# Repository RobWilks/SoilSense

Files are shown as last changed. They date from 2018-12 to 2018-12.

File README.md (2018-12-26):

# SoilSense
Measurement of capacitance of soil probe to determine moisture content of soil
Uses an LC oscillator at f from 50-100MHz
Frequency of oscillation is proportional to the inverse root of capacitance

At these frequencies and temperatures 0 < T < 30 degC the dielectric function of water is ~80; small changes in soil moisture content create a large change in capacitance

There are two physical prototypes, mark I & II:

Mark I
Uses a Clapp oscillator and emitter follower with BC547B transistors.  In the tank circuit is a toroidal inductor of 13-16 turns and 3x 22pF capacitors.
Base input and stray capacitance estimated as 7 and 3 respectively.  

Mark II
Uses a Motorola VCO MC1648 a toroidal inductor of 9 turns and 10pF cpacitor in the tank circuit (adds to input capacitance of 6pF)

Marks I & II use the same prescaler and counter circuits to convert the high frequency oscillation to a low frequency square wave, reducing the frequency by 1/2^17 

The low frequency is measured using a 16MHz 5V Promini and the result sent to a gateway using a cheap 433MHz RF transmitter 

Repository contains:

Clapp circuit 181226.log	:	LTSpice simulation of Clapp oscillator and transmission line

ReadNodeDataNew.R	:	R analysis of data from soil probe

Schematic_Soil-Sense-Mark-1_buffered-Clapp-circuit_20181225231505.pdf	:	Schematic of circuit for SoilSenseMark1 from EasyEDA

SketchVxx.cpp	:	Old - hidden

SoilSenseMark1	:	C++ code for ProMini measurement and reporting sequence

SoilSenseMark2	:	C++ code for ProMini measurement and reporting sequence

SoilSenseMark2_board.pdf	:	Vero board design for SoilSenseMark2 from Eagle

SoilSenseMark2_schematic.pdf	:	Schematic of circuit for SoilSenseMark2 from Eagle

freqCounterV4.brd	:	Vero board design for SoilSenseMark2 from Eagle

freqCounterV4.sch	:	Schematic of circuit for SoilSenseMark2 from Eagle

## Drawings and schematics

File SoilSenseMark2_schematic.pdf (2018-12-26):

100n

1u

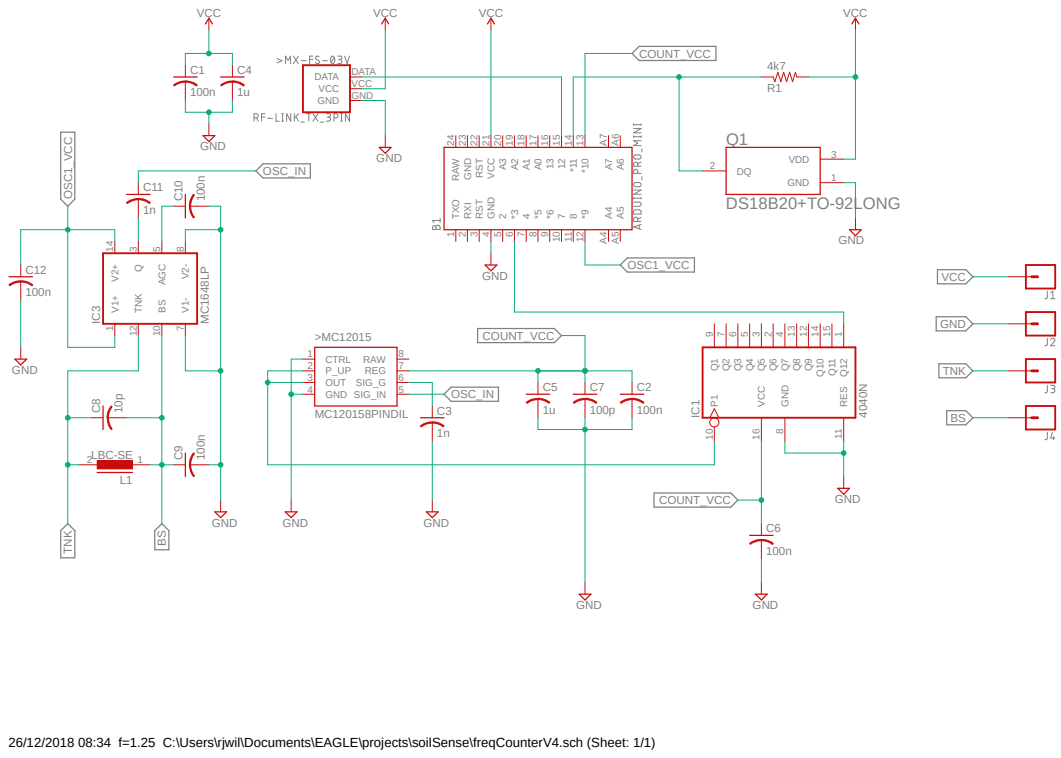
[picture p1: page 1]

26/12/2018 08:34 f=1.25 C:\Users\rjwil\Documents\EAGLE\projects\soilSense\freqCounterV4.sch (Sheet: 1/1)

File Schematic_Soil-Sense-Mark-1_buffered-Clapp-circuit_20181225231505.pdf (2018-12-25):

## probe V(Vout) V(Q4_base) V(Q4_emitter) V(Tank) tran .5n 30u 29.9u

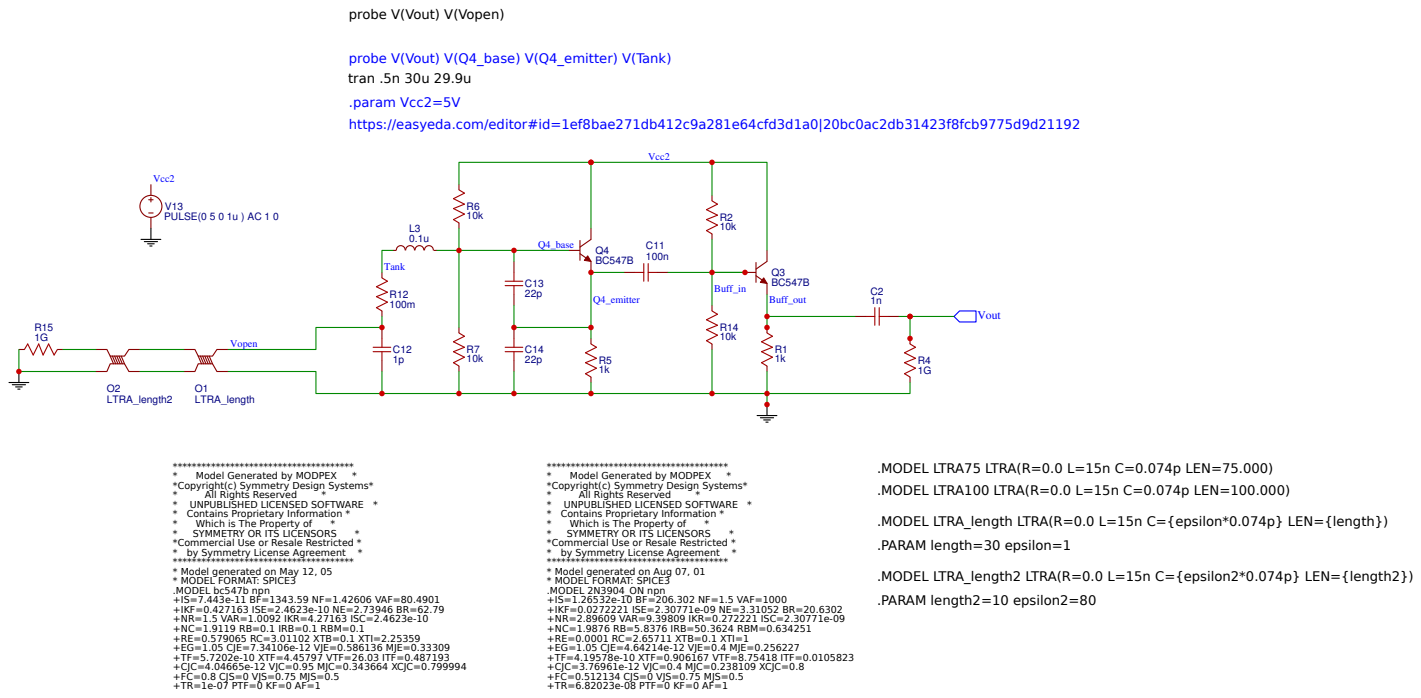
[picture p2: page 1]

.param Vcc2=5V
https://easyeda.com/editor#id=1ef8bae271db412c9a281e64cfd3d1a0|20bc0ac2db31423f8fcb9775d9d21192

*Copyright(c) Symmetry Design Systems*
* UNPUBLISHED LICENSED SOFTWARE *
* Contains Proprietary Information *
*Commercial Use or Resale Restricted *
* by Symmetry License Agreement *
* Model generated on May 12, 05
* MODEL FORMAT: SPICE3
.MODEL bc547b npn
+IS=7.443e-11 BF=1343.59 NF=1.42606 VAF=80.4901
+IKF=0.427163 ISE=2.4623e-10 NE=2.73946 BR=62.79
+NR=1.5 VAR=1.0092 IKR=4.27163 ISC=2.4623e-10
+NC=1.9119 RB=0.1 IRB=0.1 RBM=0.1
+RE=0.579065 RC=3.01102 XTB=0.1 XTI=2.25359
+EG=1.05 CJE=7.34106e-12 VJE=0.586136 MJE=0.33309
+TF=5.7202e-10 XTF=4.45797 VTF=26.03 ITF=0.487193
+CJC=4.04665e-12 VJC=0.95 MJC=0.343664 XCJC=0.799994
+FC=0.8 CJS=0 VJS=0.75 MJS=0.5
+TR=1e-07 PTF=0 KF=0 AF=1

* Model generated on Aug 07, 01
.MODEL 2N3904_ON npn
+IS=1.26532e-10 BF=206.302 NF=1.5 VAF=1000
+IKF=0.0272221 ISE=2.30771e-09 NE=3.31052 BR=20.6302
+NR=2.89609 VAR=9.39809 IKR=0.272221 ISC=2.30771e-09
+NC=1.9876 RB=5.8376 IRB=50.3624 RBM=0.634251
+RE=0.0001 RC=2.65711 XTB=0.1 XTI=1
+EG=1.05 CJE=4.64214e-12 VJE=0.4 MJE=0.256227
+TF=4.19578e-10 XTF=0.906167 VTF=8.75418 ITF=0.0105823
+CJC=3.76961e-12 VJC=0.4 MJC=0.238109 XCJC=0.8
+FC=0.512134 CJS=0 VJS=0.75 MJS=0.5
+TR=6.82023e-08 PTF=0 KF=0 AF=1

.MODEL LTRA_length LTRA(R=0.0 L=15n C={epsilon*0.074p} LEN={length})
.PARAM length=30 epsilon=1

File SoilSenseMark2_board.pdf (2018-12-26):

26/12/2018 08:36 f=3.00 C:\Users\rjwil\Documents\EAGLE\projects\soilSense\freqCounterV4.brd

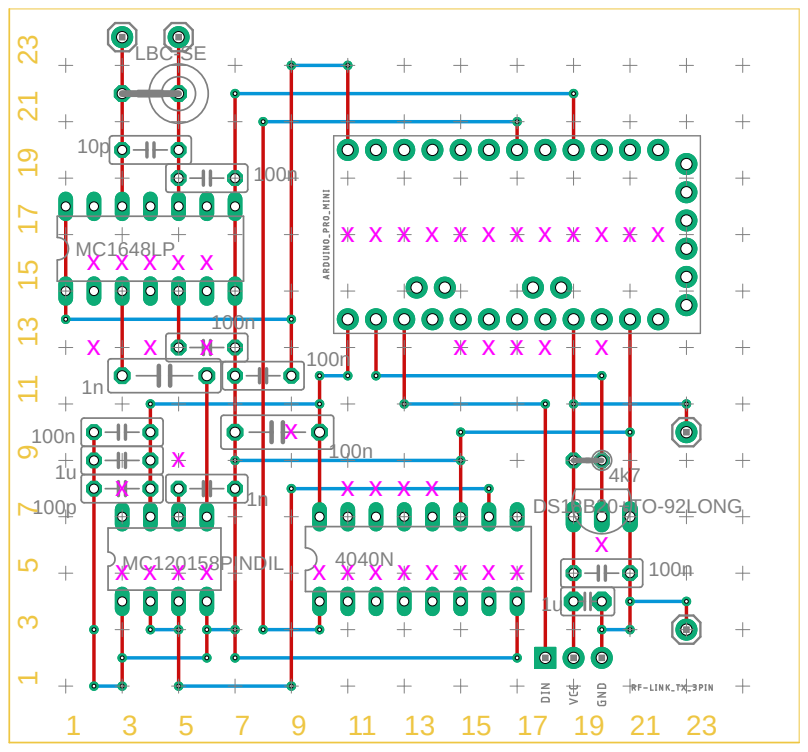
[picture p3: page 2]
MC120158PINDIL; DS18B20+TO-92LONG; LBC-SE

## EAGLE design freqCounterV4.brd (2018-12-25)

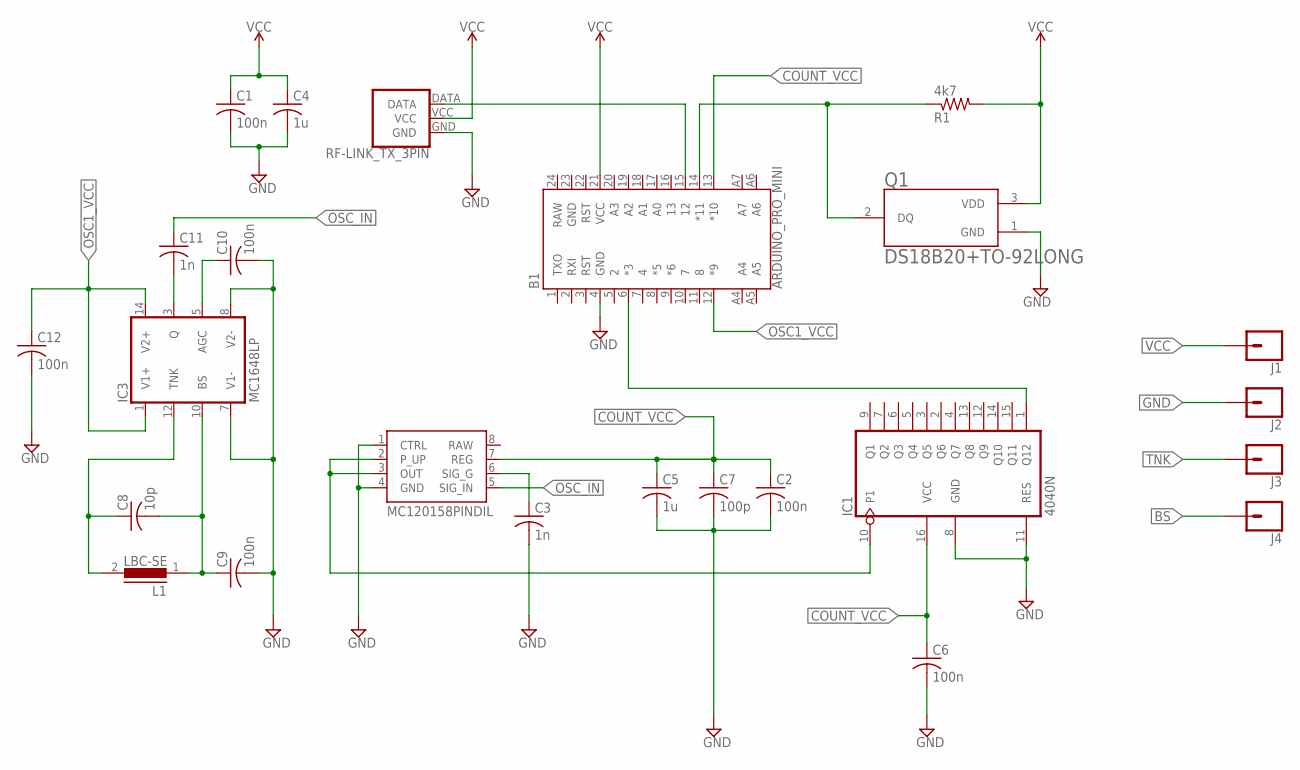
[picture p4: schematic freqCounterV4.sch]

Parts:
B1: ARDUINO_PRO_MINI
C1, C2, C9, C10, C12: 100n; C050-025X075
C3: 1n; C050-025X075
C4: 1u; C025-025X050
C5: 1u; C050-025X075
C6: 100n; C075-032X103
C7: 100p; C050-025X075
C8: 10p; C050-025X075
C11: 1n; C075-032X103
IC1: 4040N; DIL16
IC2: MC120158PINDIL; DIL08
IC3: MC1648LP; DIL14
J1, J2, J3, J4: CONN_01; 1X01
L1: LBC-SE
Q1: DS18B20+TO-92LONG; TO-92_0.1"
R1: 4k7; 0204V
U$2: RF-LINK_TX_3PIN

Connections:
BS: C8.2, C9.1, IC3.10 (BS), J4.1, L1.1
COUNT_VCC: B1.13 (*10), C2.1, C5.1, C6.1, C7.1, IC1.16 (VCC), IC2.7 (REG)
GND: B1.4 (GND), B1.23 (GND), C1.2, C2.2, C3.2, C4.2, C5.2, C6.2, C7.2, C9.2, C10.2, C12.2, IC1.8 (GND), IC1.11 (RES), IC2.1 (CTRL), IC2.4 (GND), IC3.7 (V1-), IC3.8 (V2-), J2.1, Q1.1 (GND), U$2.GND
unnamed: IC1.10 (P1), IC2.2 (P_UP), IC2.3 (OUT)
unnamed: C3.1, IC2.6 (SIG_G)
unnamed: B1.6 (*3), IC1.1 (Q12)
unnamed: C11.2, IC3.3 (Q)
unnamed: B1.15 (12), U$2.DATA
unnamed: B1.14 (*11), Q1.2 (DQ), R1.1
unnamed: C10.1, IC3.5 (AGC)
OSC1_VCC: B1.12 (*9), C12.1, IC3.1 (V1+), IC3.14 (V2+)
OSC_IN: C11.1, IC2.5 (SIG_IN)
RAW: B1.24 (RAW), IC2.8 (RAW)
TNK: C8.1, IC3.12 (TNK), J3.1, L1.2
VCC: B1.21 (VCC), C1.1, C4.1, J1.1, Q1.3 (VDD), R1.2, U$2.VCC

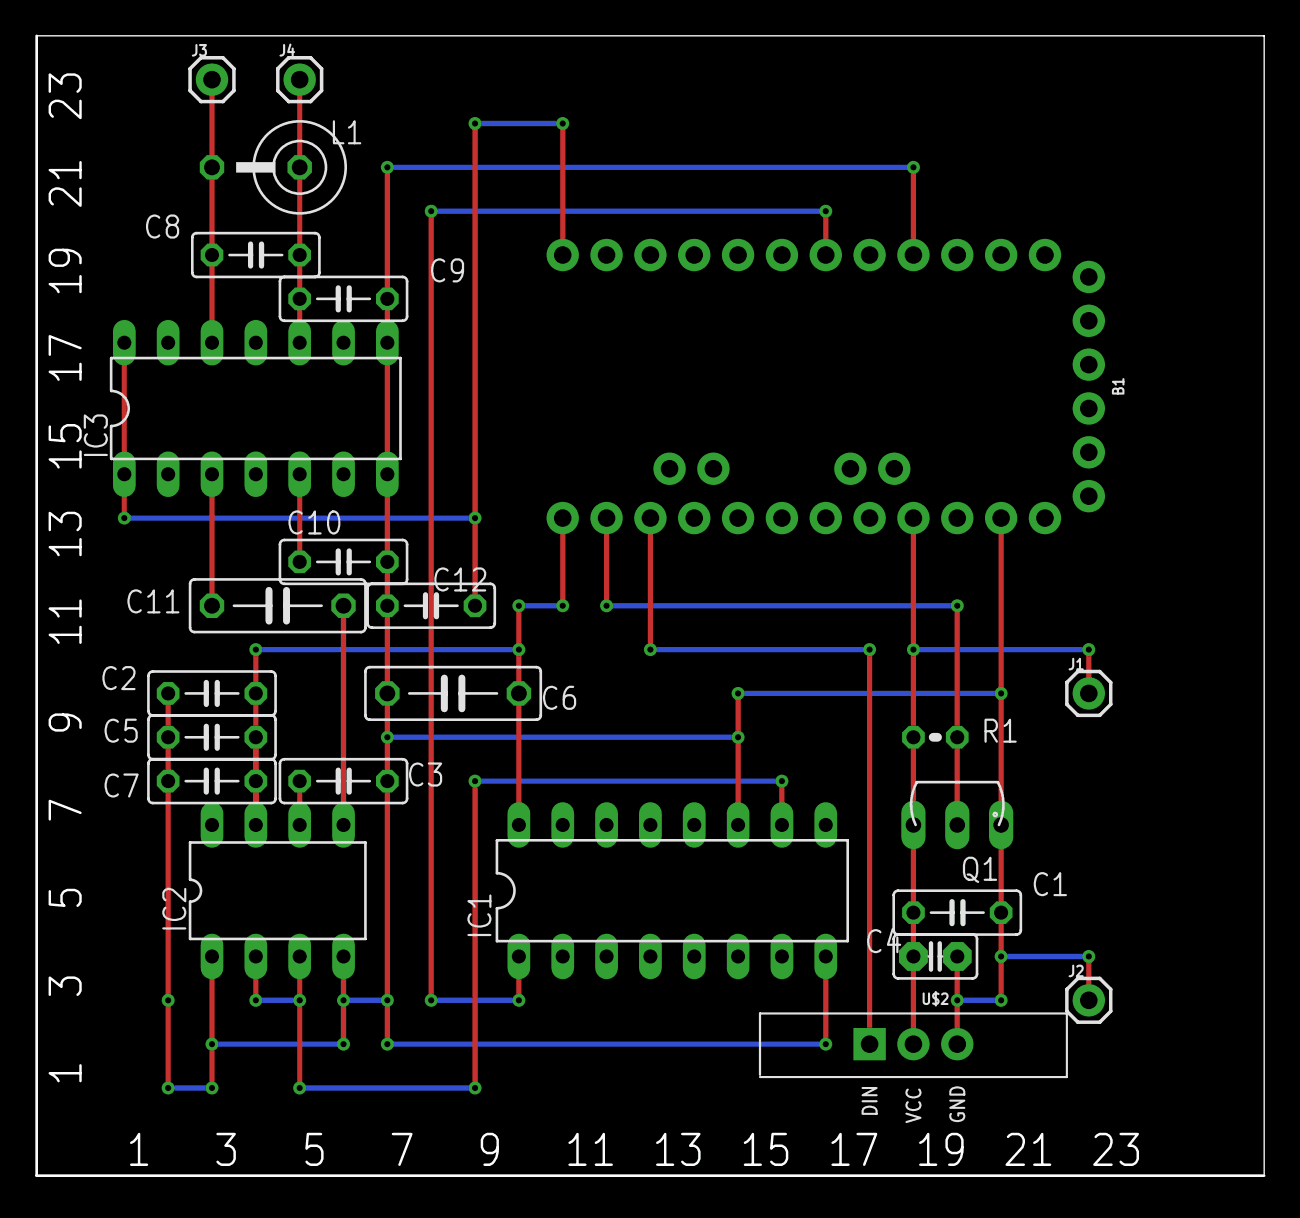
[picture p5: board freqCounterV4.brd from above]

Board: 2 copper layers, 71.1 x 66.0 mm, 24 parts (0 on the bottom side), 15 nets.

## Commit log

2018-12-25 Create SoilSenseMark1
    Mark1 2x Clapp oscillator: 1) reference oscillator and 2) oscillator with soil probe in LC tank
2018-12-25 Add files via upload
    EasyEDA schematic for mark 1 soil sense used for circuit simulation
    Original file: https://easyeda.com/editor#id=1ef8bae271db412c9a281e64cfd3d1a0|20bc0ac2db31423f8fcb9775d9d21192
2018-12-25 Add files via upload
    Eagle files for soil sensor Mark 2
    [freqCounterV4.brd, freqCounterV4.sch]

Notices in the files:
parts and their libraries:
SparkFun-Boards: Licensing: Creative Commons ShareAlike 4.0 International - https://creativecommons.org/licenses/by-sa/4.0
